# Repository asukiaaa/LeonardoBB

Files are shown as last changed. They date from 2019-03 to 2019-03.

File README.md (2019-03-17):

# LeonardoBB

PCB to use an Arduino Leonardo and a bread board together.

# License
MIT

# References
- [PDF: Arduino LEONARDO Schematic](https://www.arduino.cc/en/uploads/Main/arduino-leonardo-schematic_3b.pdf)
- [PDF: Arduino Pro Micro](https://cdn.sparkfun.com/datasheets/Dev/Arduino/Boards/Pro_Micro_v13b.pdf)

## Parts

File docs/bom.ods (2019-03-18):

symbol | spec | number | url
C1,C2 | 0402inch 22pf | 2 | https://www.digikey.jp/product-detail/ja/avx-corporation/04025A220JAT2A/478-1074-1-ND/564106
C3,C5,C7 | 0402inch 100nf | 3 | https://www.digikey.jp/product-detail/ja/murata-electronics-north-america/GRM155R71C104KA88J/490-6328-1-ND/3845525
C4,C6,C10 | 0402inch 1u | 3 | https://www.digikey.jp/product-detail/ja/taiyo-yuden/LMK105BJ105KV-F/587-1454-1-ND/1004085
C8,C9 | 0805inch 10uf | 2 | https://www.digikey.jp/product-detail/ja/murata-electronics-north-america/GRM21BC81C106KE15L/490-10498-1-ND/5026423
C12 | 0402inch 10nf | 1 | https://www.digikey.jp/product-detail/ja/murata-electronics-north-america/GRM155R71E103KA01D/490-1312-1-ND/587934
C13 | 0402inch 2.2u | 1 | https://www.digikey.jp/product-detail/ja/murata-electronics-north-america/GRM155R61A225KE95D/490-10451-1-ND/5026361
D1 | SMA 50V1A | 1 | https://www.digikey.jp/product-detail/ja/diodes-incorporated/S1A-13-F/S1A-FDICT-ND/750031
D2 | 0603inch green | 1
DZ1,DZ2 | 0603inch 5v | 2 | https://www.digikey.jp/product-detail/ja/bourns-inc/CG0603MLC-05E/CG0603MLC-05ECT-ND/3438061
FB1 | 0805inch 3A | 1 | https://www.digikey.jp/product-detail/ja/bourns-inc/MH2029-300Y/MH2029-300YCT-ND/3741761
J1 | USB microB | 1 | https://www.digikey.jp/product-detail/ja/amphenol-icc-fci/10103594-0001LF/609-4050-1-ND/2350357
J2,J3 | 2.54mm 1x17 PinSocket | 2
J4 | Groove 2mm Vertical | 1 | https://www.digikey.jp/product-detail/ja/seeed-technology-co-ltd/110990030/1597-1082-ND/5482560
Q1 | SuperSOT-3 p-ch mosfet | 1 | https://www.digikey.jp/product-detail/ja/on-semiconductor/FDN340P/FDN340PCT-ND/965604
Q2 | SOT-363 2p-ch mosfet | 1 | https://www.digikey.jp/product-detail/ja/on-semiconductor/NTJD4152PT1G/NTJD4152PT1GOSCT-ND/687124
R1,R4,R5,R6,R8,R9,R10 | 0603inch 10k | 7
R2,R3 | 0603inch 22 | 2 | https://www.digikey.jp/product-detail/ja/rohm-semiconductor/ESR03EZPJ220/RHM22DCT-ND/1983787
R7 | 0603inch 1k | 1
SW1 | PCM12 | 1 | https://www.digikey.jp/product-detail/ja/c-k/PCM12SMTR/401-2016-1-ND/1640125
U1 | atmega32u4-mu | 1 | https://www.digikey.jp/product-detail/ja/microchip-technology/ATMEGA32U4-MUR/ATMEGA32U4-MURCT-ND/3440961
U2 | LMV358 | 1 | https://www.digikey.jp/product-detail/ja/texas-instruments/LMV358IDGKR/296-13455-1-ND/486370
U3 | NCP1117-5.0 | 1 | https://www.digikey.jp/product-detail/ja/on-semiconductor/NCP1117ST50T3G/NCP1117ST50T3GOSCT-ND/1967217
U4 | LP2985-3.3 | 1 | https://www.digikey.jp/product-detail/ja/texas-instruments/LP2985-33DBVR/296-18476-2-ND/809759
Y1 | 16MHz | 1 | https://www.digikey.jp/product-detail/ja/epson/TSX-3225-16.0000MF09Z-AC0/SER4069CT-ND/5413938
Deleted | C11

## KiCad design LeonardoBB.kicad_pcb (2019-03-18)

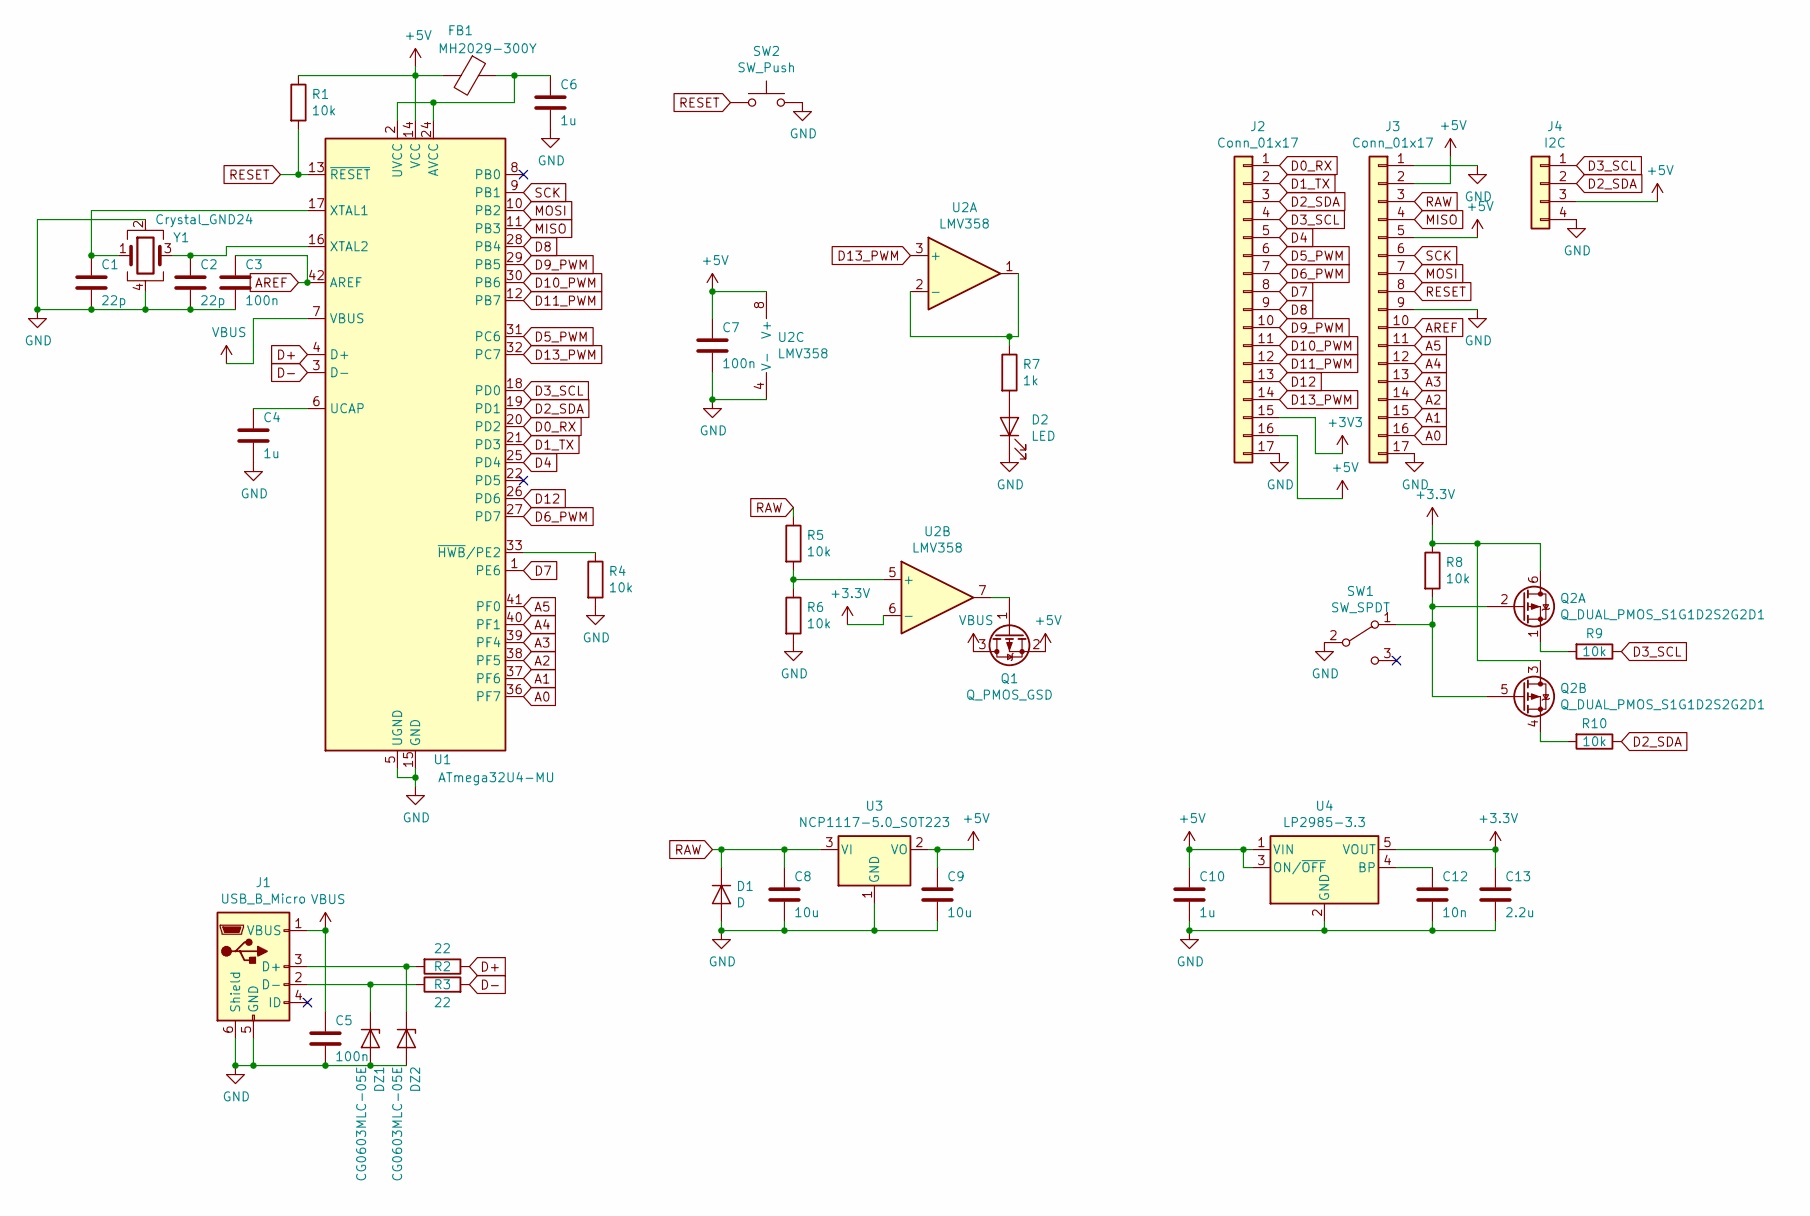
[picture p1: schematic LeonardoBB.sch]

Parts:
C1, C2: 22p; C_0402_1005Metric
C3, C5, C7: 100n; C_0402_1005Metric
C4, C6, C10: 1u; C_0402_1005Metric
C8, C9: 10u; C_0805_2012Metric
C12: 10n; C_0402_1005Metric
C13: 2.2u; C_0402_1005Metric
D1: D; D_SMA
D2: LED; LED_0603_1608Metric
DZ1, DZ2: CG0603MLC-05E; D_0603_1608Metric
FB1: MH2029-300Y; C_0805_2012Metric
J1: USB_B_Micro; USB_Micro-B_Molex-105017-0001
J2, J3: Conn_01x17; PinSocket_1x17_P2.54mm_Vertical_without_silk
J4: I2C; NS-Tech_Grove_1x04_P2mm_Vertical
Q1: Q_PMOS_GSD; SuperSOT-3
Q2: Q_DUAL_PMOS_S1G1D2S2G2D1; SOT-363_SC-70-6
R1, R4, R5, R6, R8, R9, R10: 10k; R_0603_1608Metric
R2, R3: 22; R_0603_1608Metric
R7: 1k; R_0603_1608Metric
SW1: SW_SPDT; SW_SPDT_PCM12
SW2: SW_Push; SW_SPST_PTS810
U1: ATmega32U4-MU; QFN-44-1EP_7x7mm_P0.5mm_EP5.2x5.2mm
U2: LMV358; VSSOP-8_3.0x3.0mm_P0.65mm
U3: NCP1117-5.0_SOT223; SOT-223-3_TabPin2
U4: LP2985-3.3; SOT-23-5
Y1: Crystal_GND24; Crystal_SMD_SeikoEpson_TSX3225-4Pin_3.2x2.5mm

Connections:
+5V: C7.1, C9.1, C10.1, FB1.2, J2.16, J3.2, J3.5, J4.3, Q1.2 (S), R1.1, U1.14 (VCC), U1.34 (VCC), U2.8 (V+), U3.2 (VO), U4.1 (VIN), U4.3 (ON/~OFF~)
A0: J3.16, U1.36 (PF7)
A1: J3.15, U1.37 (PF6)
A2: J3.14, U1.38 (PF5)
A3: J3.13, U1.39 (PF4)
A4: J3.12, U1.40 (PF1)
A5: J3.11, U1.41 (PF0)
AREF: C3.1, J3.10, U1.42 (AREF)
D0_RX: J2.1, U1.20 (PD2)
D1_TX: J2.2, U1.21 (PD3)
D2_SDA: J2.3, J4.2, R10.1, U1.19 (PD1)
D3_SCL: J2.4, J4.1, R9.1, U1.18 (PD0)
D4: J2.5, U1.25 (PD4)
D5_PWM: J2.6, U1.31 (PC6)
D6_PWM: J2.7, U1.27 (PD7)
D7: J2.8, U1.1 (PE6)
D8: J2.9, U1.28 (PB4)
D9_PWM: J2.10, U1.29 (PB5)
D10_PWM: J2.11, U1.30 (PB6)
D11_PWM: J2.12, U1.12 (PB7)
D12: J2.13, U1.26 (PD6)
D13_PWM: J2.14, U1.32 (PC7), U2.3 (+)
D+: R2.1, U1.4 (D+)
D-: R3.2, U1.3 (D-)
GND: C1.2, C2.2, C3.2, C4.2, C5.2, C6.2, C7.2, C8.2, C9.2, C10.2, C12.2, C13.2, D1.2 (A), D2.1 (K), DZ1.2 (A), DZ2.2 (A), J1.5 (GND), J1.6 (Shield), J2.17, J3.1, J3.9, J3.17, J4.4, R4.2, R6.2, SW1.2 (B), SW2.2, U1.5 (UGND), U1.15 (GND), U1.23 (GND), U1.35 (GND), U1.43 (GND), U1.45 (GND), U2.4 (V-), U3.1 (GND), U4.2 (GND), Y1.2, Y1.4
MISO: J3.4, U1.11 (PB3)
MOSI: J3.7, U1.10 (PB2)
unnamed: C1.1, U1.17 (XTAL1), Y1.1
unnamed: C2.1, U1.16 (XTAL2), Y1.3
unnamed: C4.1, U1.6 (UCAP)
unnamed: C6.1, FB1.1, U1.2 (UVCC), U1.24 (AVCC), U1.44 (AVCC)
unnamed: C12.1, U4.4 (BP)
unnamed: D2.2 (A), R7.2
unnamed: DZ1.1 (K), J1.2 (D-), R3.1
unnamed: DZ2.1 (K), J1.3 (D+), R2.2
unnamed: Q1.1 (G), U2.7
unnamed: Q2.1 (S), R9.2
unnamed: Q2.2 (G), Q2.5 (G), R8.2, SW1.1 (A)
unnamed: Q2.4 (S), R10.2
unnamed: R4.1, U1.33 (~HWB~/PE2)
unnamed: R5.2, R6.1, U2.5 (+)
unnamed: R7.1, U2.1, U2.2 (-)
RAW: C8.1, D1.1 (K), J3.3, R5.1, U3.3 (VI)
RESET: J3.8, R1.2, SW2.1, U1.13 (~RESET)
SCK: J3.6, U1.9 (PB1)
VBUS: C5.1, J1.1 (VBUS), Q1.3 (D), U1.7 (VBUS)

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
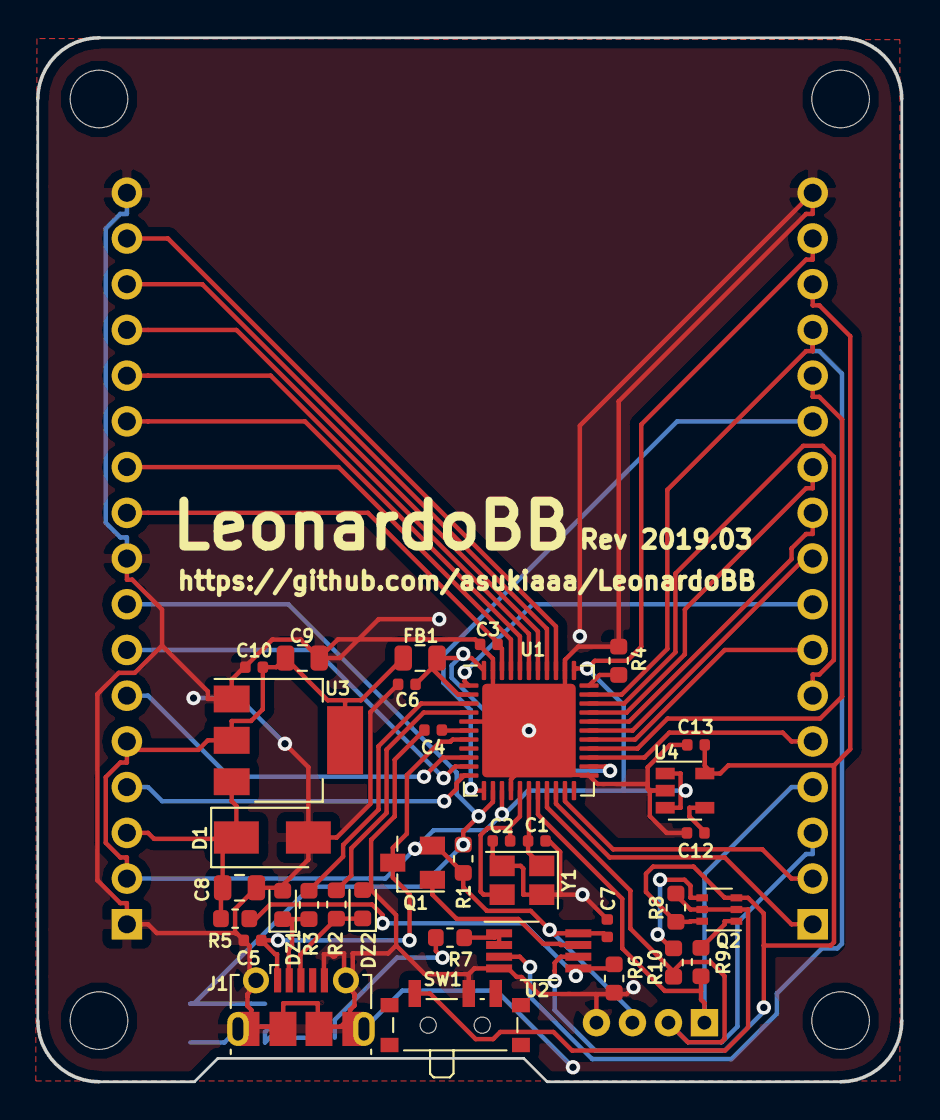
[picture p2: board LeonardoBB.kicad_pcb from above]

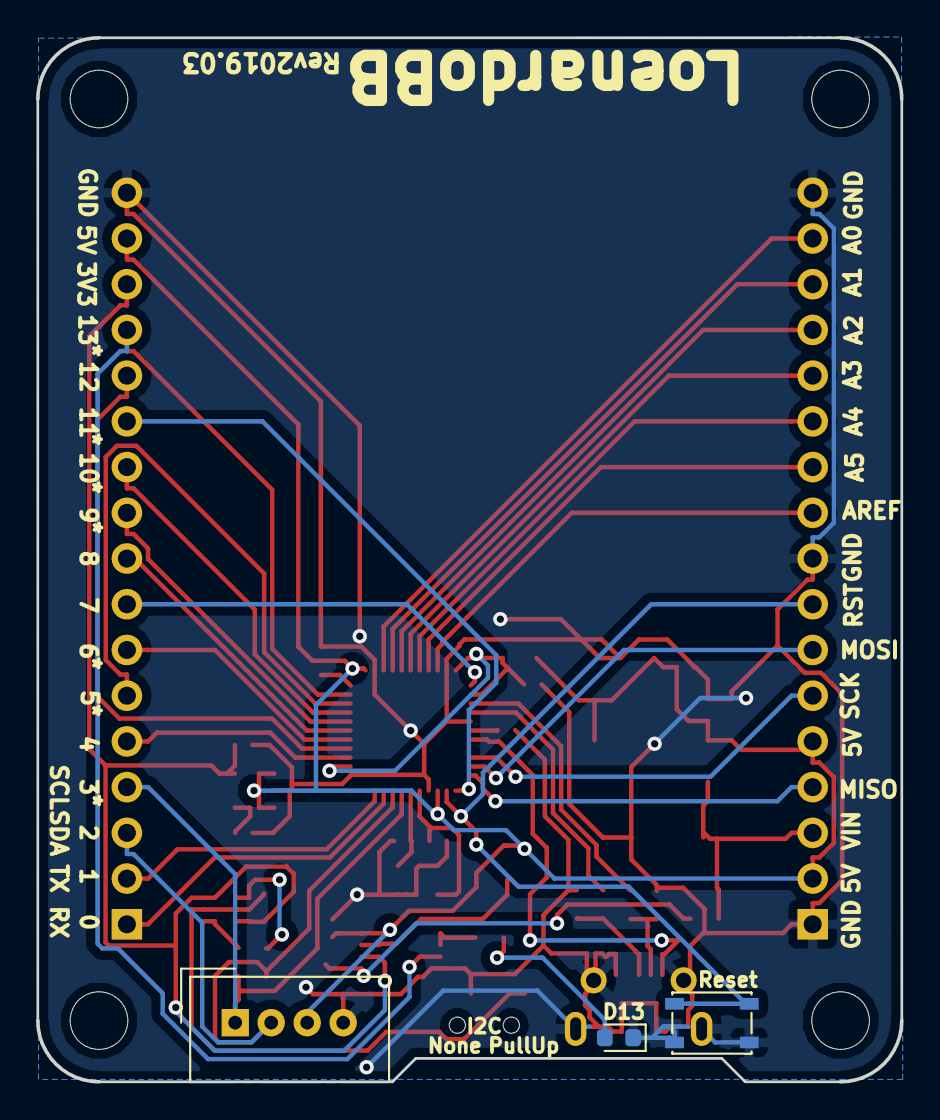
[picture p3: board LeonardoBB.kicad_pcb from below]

Board: 2 copper layers, 48.0 x 58.0 mm, 44 parts (5 on the bottom side), 47 nets.

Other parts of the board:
REF1, REF2, REF3, REF4: MountingHole_3.2mm_M3

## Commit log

2019-03-17 Change footprints for USB and LMV358
    [LeonardoBB.kicad_pcb, LeonardoBB.sch]
2019-03-17 Update silks as revision 2019.03
    [LeonardoBB.kicad_pcb]
2019-03-17 Update gerber files to order for fusion PCB
    [LeonardoBB-B.Cu.gbl, LeonardoBB-B.Mask.gbs, LeonardoBB-B.Paste.gbp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]
2019-03-18 Add reset switch
    [LeonardoBB-B.Cu.gbl, LeonardoBB-B.Mask.gbs, LeonardoBB-B.Paste.gbp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]
